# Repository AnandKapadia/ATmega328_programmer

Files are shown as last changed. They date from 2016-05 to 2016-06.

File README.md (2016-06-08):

AT Programming Shield
==========

##BOM
* Shield Board (eagle schematic provided)
* Arduino Uno
* Chip to Program, either an ATTiny85, ATmega328P-PU, ATmega328P(TQFP)
* 16Mhz Crystal
* Capacitors for Crytsal (22 pF) x2
* 10uF Cap 
* 10k Resistor (0603)
* 330 Resistor (0603)
* 4 Slide Switches
* SMD LED (1206)
For a detailed list please see the BOM

##Here is what the shield looks like. 

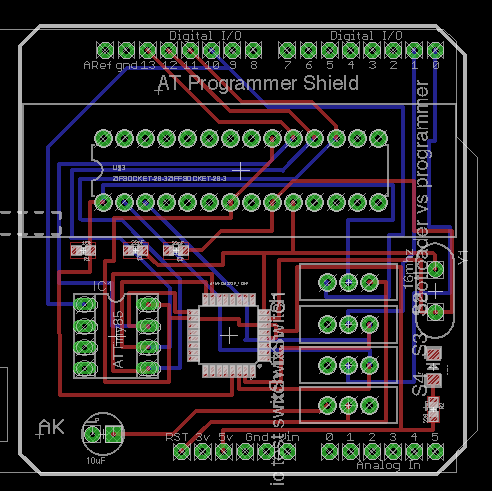
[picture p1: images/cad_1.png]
CAD 1


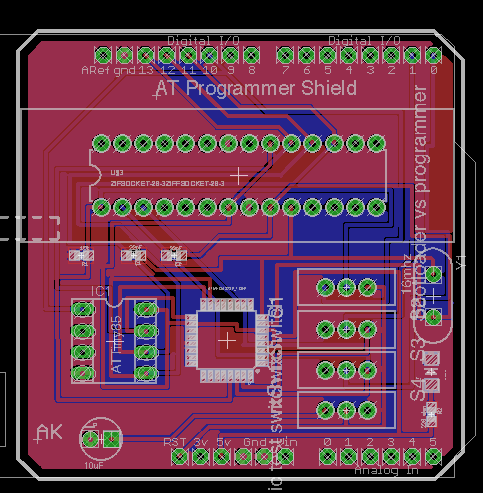
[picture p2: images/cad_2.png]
CAD 2


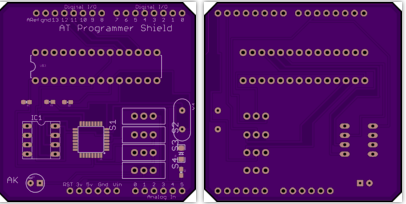
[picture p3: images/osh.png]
OSH Park


Image: 


Soldered: 


##How To Use
NOTE: You can only program one board at a time. 

From top to bottom, here is what each switch does. 
* Switch 1 (Connection to Pin 1 of ATMega): Arduino 10 <--> Arduino Reset
* Switch 2 (Connection to Pin 3 of ATMega): Disconnected <--> Arduino TX
* Switch 3 (Conenction to Pin 2 of ATMega): Disconnected <--> Arduino RX
* Switch 4 : Arduino Reset connected to Capacitor (10uF) <--> Disconnected

For ATtiny85: 
* Switches 1-3 : Does not matter
* Switch 4 : To the Left (Reset connected to Cap)

For Bootloader onto ATMega (both forms):
* Switch 1: To the left (Arduino 10)
* Switch 2/3: To the left (Disconnected)
* Switch 4: To the right (Disconnected)
    
For Programming onto ATMega (both forms):
* Switch 1: To the Right (Arduino Reset)
* Switch 2/3: To the Right (Rx/Tx)
* Switch 4: To the right (Disconnected)
* Note: Remove the arduino's built in mega chip to do this.

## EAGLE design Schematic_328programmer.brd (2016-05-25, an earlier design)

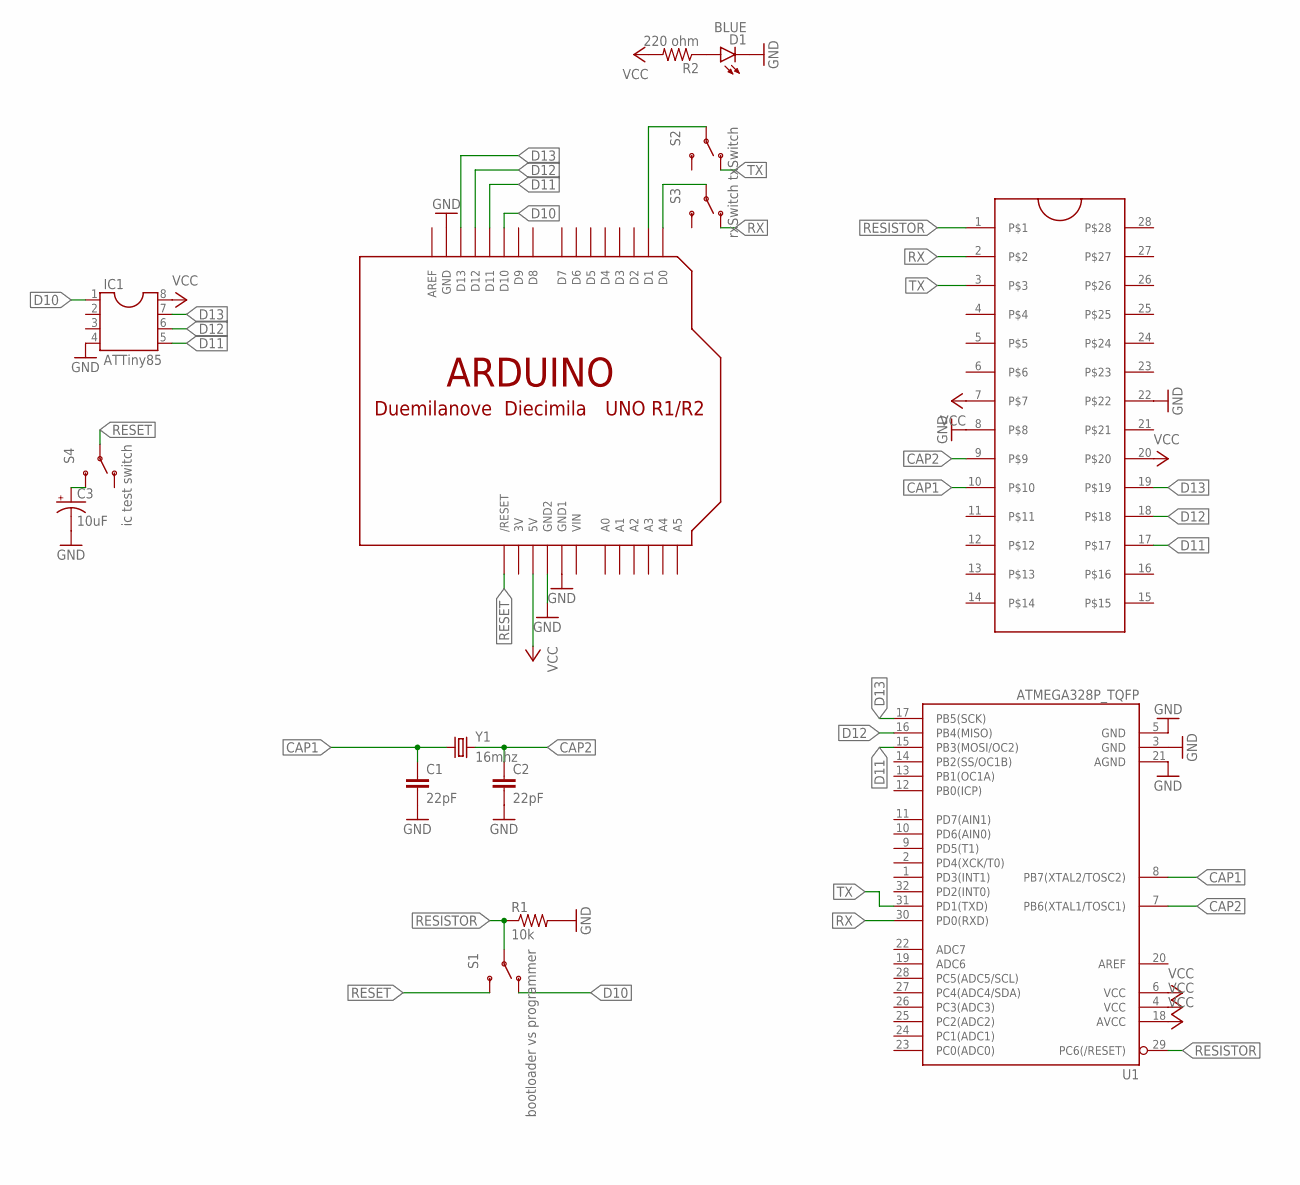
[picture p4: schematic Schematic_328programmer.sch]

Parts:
C1, C2: 22pF; 0603-CAP
C3: 10uF; CPOL-RADIAL-10UF-25V
D1: BLUE; LED-1206
IC1: ATTiny85; SOCKET-08
R1: 10k; 0603-RES
R2: 220 ohm; 0603-RES
S1: bootloader vs programmer; SWITCH-SPDT
S2: txSwitch; SWITCH-SPDT
S3: rxSwitch; SWITCH-SPDT
S4: ic test switch; SWITCH-SPDT
U1: ATMEGA328P_TQFP; TQFP32-08
U$1: ARDUINOUNO; ARDUINO
U$3: ZIFSOCKET-28-3ZIFFSOCKET-28-3; DIL28-3-ZIF_SOCKET
Y1: 16mhz; HC49US

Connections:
3V: U$1.3V
CAP1: C1.1, U1.8 (PB7(XTAL2/TOSC2)), U$3.10, Y1.1
CAP2: C2.1, U1.7 (PB6(XTAL1/TOSC1)), U$3.9, Y1.2
D10: IC1.1, S1.1 (O), U$1.D10
D11: IC1.5, U1.15 (PB3(MOSI/OC2)), U$1.D11, U$3.17
D12: IC1.6, U1.16 (PB4(MISO)), U$1.D12, U$3.18
D13: IC1.7, U1.17 (PB5(SCK)), U$1.D13, U$3.19
GND: C1.2, C2.2, C3.2 (-), D1.C, IC1.4, R1.2, U1.3 (GND), U1.5 (GND), U1.21 (AGND), U$1.GND, U$1.GND1, U$1.GND2, U$3.8, U$3.22
unnamed: D1.A, R2.1
unnamed: S3.2, U$1.D0
unnamed: S2.2, U$1.D1
unnamed: C3.1 (+), S4.3 (S)
RESET: S1.3 (S), S4.2, U$1.RESET (/RESET)
RESISTOR: R1.1, S1.2, U1.29 (PC6(/RESET)), U$3.1
RX: S3.1 (O), U1.30 (PD0(RXD)), U$3.2
TX: S2.1 (O), U1.31 (PD1(TXD)), U$3.3
VCC: IC1.8, R2.2, U1.4 (VCC), U1.6 (VCC), U1.18 (AVCC), U$1.5V, U$3.7, U$3.20
VIN: U$1.VIN

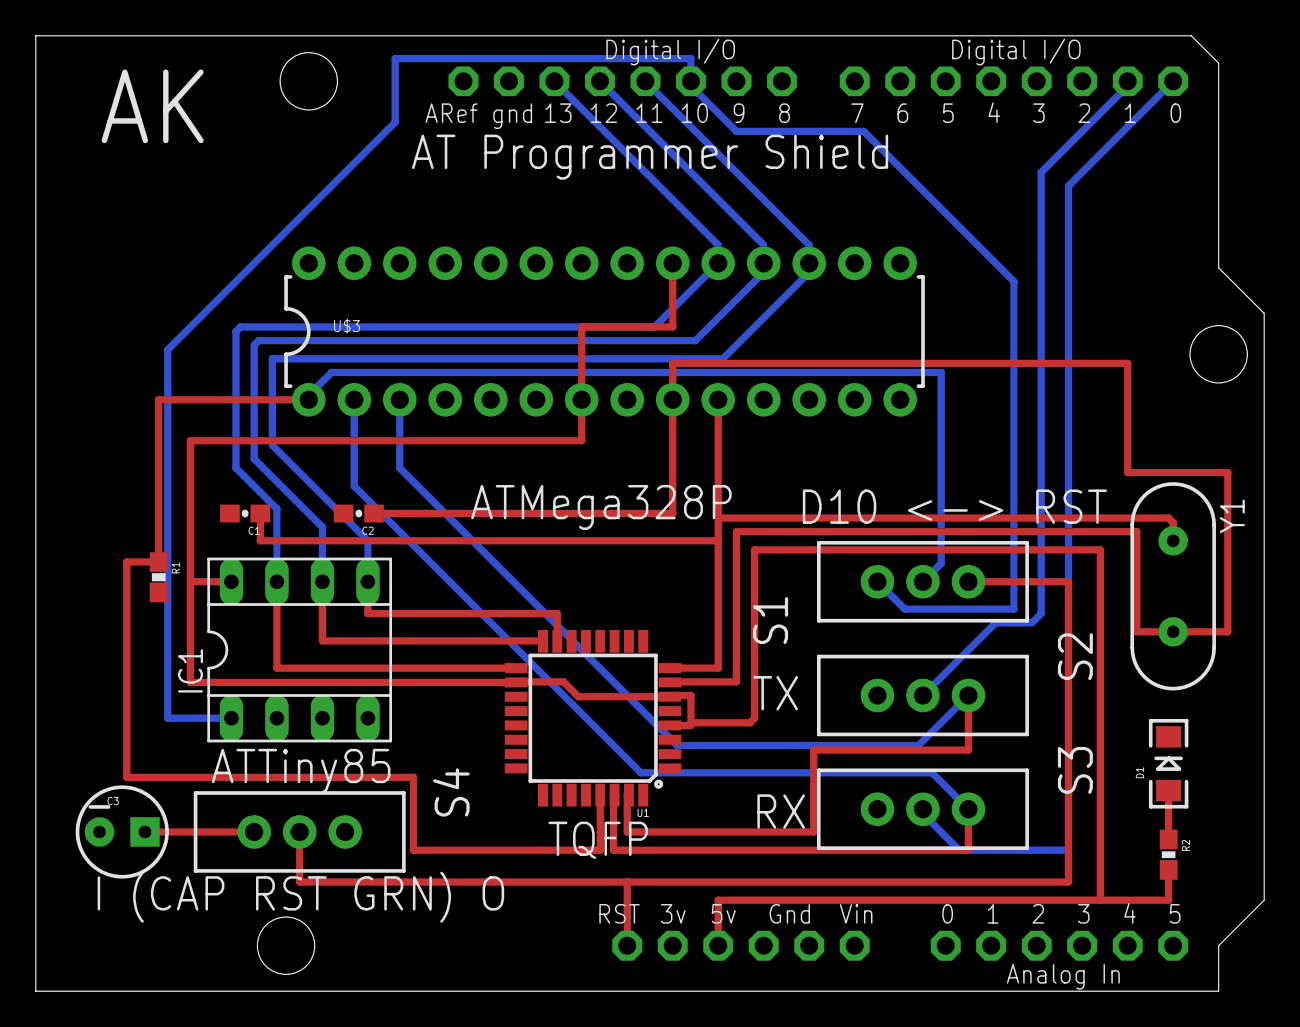
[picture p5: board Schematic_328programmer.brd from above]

Board: 2 copper layers, 68.6 x 53.3 mm, 15 parts (0 on the bottom side), 16 nets.

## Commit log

2016-05-25 Uploaded Eagle Board and Schematic
    Sparkfun and Adafruit libraries were used in this project.
    [Schematic_328programmer.brd, Schematic_328programmer.sch]
2016-06-08 Updated Board CAD files
    [Schematic_328programmer.sch, Schematic_328programmer_v0.2.brd, Schematic_328programmer_v0.3.brd]

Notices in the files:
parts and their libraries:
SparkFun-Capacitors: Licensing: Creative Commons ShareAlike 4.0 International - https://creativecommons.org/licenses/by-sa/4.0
